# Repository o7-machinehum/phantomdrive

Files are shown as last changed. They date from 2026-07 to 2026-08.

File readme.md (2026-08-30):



Phantomdrive is open source encrypted USB drive with a stealth mechanism to hide its second partition. To decrypt it you must create a file containing your password in the format `password:addpasswordhere`, this is used to derive AES-XTS keys. The drive automatically unmounts itself, remounts the remaining disk and encrypts and decrypts in place. It uses CH569W SoC, which has USB3, SDIO and an AES hardware block. It is programmable over USB using the `wch-ch56x-isp` library.

``` bash
|-- ee             # Hardware files
|-- Makefile
|-- readme.md      # This files
|-- test           # Test the cypto components
|-- ref            # Reference docs
|-- src            # Firmware
|-- tests          # Verification scripts
|-- wch-ch56x-bsp  # Board support package
`-- wch-ch56x-isp  # Programming software
```

# Getting Started
``` bash
git submodule update --init --recursive --checkout --force
cd wch-ch56x-isp
make # Build the ISP tool
```

## Install the toolchain
The HydraUSB3 project requires the patched HydraUSB3 xPack GCC 12.2.0-1, which
supports the `WCH-Interrupt-fast` interrupt attribute:

```bash
cd /tmp
curl -sL -o riscv-gcc-xpack.tar.gz \
  "https://github.com/hydrausb3/riscv-none-elf-gcc-xpack/releases/download/12.2.0-1/xpack-riscv-none-elf-gcc-12.2.0-1-linux-x64.tar.gz"
tar xzf riscv-gcc-xpack.tar.gz
sudo cp -r xpack-riscv-none-elf-gcc-12.2.0-1/* /usr/local/
```

## Debugging
```
make UART=1 # Enable UART
```

## Build and Flashing the project

The AES mode, PBKDF2 iteration count, and locked capacity can be selected
independently. Supported KDF values are `100000` and `600000`; 100,000 is the
default. `LOCKED_SECTORS` sets the locked (decoy) capacity in 512-byte sectors
and defaults to 16,777,216 sectors (8 GiB). It must be smaller than the physical
card's sector count; otherwise the unlocked capacity calculation underflows.

``` bash
# Remove flash drive
# While holding boot button, plug in

# Build and flash AES-XTS firmware with 600,000 PBKDF2 iterations and an
# 8 GiB locked capacity
make AES_MODE=XTS KDF_ROUNDS=600000 LOCKED_SECTORS=16777216 flash

# Or build and flash AES-CTR firmware with 100,000 iterations
make AES_MODE=CTR KDF_ROUNDS=100000 flash

# Build all four AES/KDF combinations
./release.sh
```

The four builds are written to `build/CTR_100K`, `build/CTR_600K`,
`build/XTS_100K`, and `build/XTS_600K`.

## Unlocking Drive
``` bash
# This will keep your password in bash history, but fine for testing/insecure
sudo echo "password:YourPasswordHere13245" > /mnt/unlock.txt

# Or avoid keeping the password is bash history
sudo dd of=/mnt/unlock.txt
password:YourPasswordHere13245
^D # ctrl+d
```
On the same note, please ensure your text editor doesn't cash/backup files, if they do disable that or use a different editor.

# Releasing the hardware
``` bash
./scripts/release_hardware.sh
```

# Security Notes

This code has not been professionally audited. Treat Phantomdrive as an experimental open source hardware/firmware project rather than a formally reviewed security product. The current level of validation is described in the [test README](test/readme.md). I am not responsible for loss of data, security incidents, or other damage resulting from use of this project.

The encrypted area can use AES-256-CTR or AES-256-XTS, with keys derived using
PBKDF2-HMAC-SHA256 and either 100,000 or 600,000 iterations. AES mode and KDF
iteration count affect the on-disk format, so firmware built with different
settings cannot decrypt the same data without migration or reformatting.

Unlock detection is also content-based. While the device is locked, any write data containing the string `password:` can be interpreted as an unlock attempt; the file does not need to be named `unlock.txt`.

Shells may save commands in history so be aware when unlocking from the shell. Additionally, some text editors cache file contents in swap, autosave, or recovery files, etc... If you're using a text editor to enter your password disable this feature.

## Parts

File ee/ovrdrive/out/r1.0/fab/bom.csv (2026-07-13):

Designator | Value | Footprint | Quantity | Part Number
C1,C6 | 4.7uF | Capacitor_SMD:C_0402_1005Metric | 2 | CL05A475MP5NRNC
C3,C4,C8,C10,C14-C18,C21-C23,C26-C28 | 100nF | Capacitor_SMD:C_0402_1005Metric | 15 | CL05B104KP5NNNC
C7,C9,C11,C12 | 22uF | Capacitor_SMD:C_0402_1005Metric | 4 | CL05A226MQ5N6J8
C19,C20 | 15pF | Capacitor_SMD:C_0402_1005Metric | 2 | CL05C150JB5NNNC
C24,C25 | 2.2uF | Capacitor_SMD:C_0402_1005Metric | 2 | CL05A225MQ5NNNC
J2 | USB3_A | Connector_USB:USB3_A_Plug_Wuerth_692112030100_Horizontal | 1 | XUSM-0930-231
J4 | Micro_SD_Card_Det_Hirose_DM3AT | Connector_Card:microSD_HC_Hirose_DM3AT-SF-PEJM5 | 1 | DM3AT-SF-PEJM5
L1,L2 | 2.2uH | Inductor_SMD:L_Changjiang_FTC303015D | 2 | SRN3015-2R2M
R1,R2,R4,R5 | 100k | Capacitor_SMD:C_0402_1005Metric | 4 | RC0402FR-07100KL
R3 | 450k | Capacitor_SMD:C_0402_1005Metric | 1 | RC0402FR-07453KL
RN1,RN2 | 47k | Resistor_SMD:R_Array_Concave_4x0402 | 2 | CAT10-473J4LF
SW1 | SW_Push | Button_Switch_SMD:SW_Push_SPST_NO_Alps_SKRK | 1 | SKRKAEE020
U1 | CH569W | Package_DFN_QFN:QFN-68-1EP_8x8mm_P0.4mm_EP5.2x5.2mm | 1 | CH569W
U2,U3 | TLV62569DBV | Package_TO_SOT_SMD:SOT-23-5 | 2 | TLV62569DBV
U5-U7 | TPD2EUSB30 | Package_TO_SOT_SMD:Texas_DRT-3 | 3 | TPD2EUSB30DRTR
Y2 | 30Mhz | Crystal:Crystal_SMD_3225-4Pin_3.2x2.5mm | 1 | ABM8-30.000MHZ-12-B1U-T

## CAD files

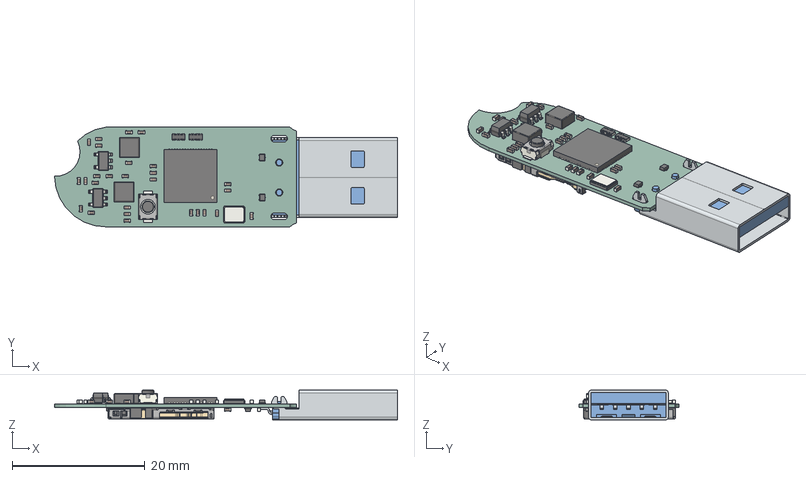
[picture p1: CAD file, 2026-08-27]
ee/ovrdrive/out/r1.0/ovrdrive.step
51.6 x 15.0 x 4.50 mm
C_0402_1005Metric x 33
DRT_3 x 3
SOT-23-5 x 2
R_Array_Concave_4x0402 x 2
L_Changjiang_FTC303015D x 2
SW_Push_SPST_NO_Alps_SKRK
Crystal_SMD_3225-4Pin_3.2x2.5mm
QFN_68_1EP_8x8mm_P04mm_EP52x52mm
microSD_HC_Hirose_DM3AT-SF-PEJM5
692112030100_Housing
692112030100_Shielding
692112030100_Pin2
692112030100_Pin3 x 2
692112030100_Pin1 x 5
692112030100_Housing2
692112030100_Pin5
ovrdrive_PCB

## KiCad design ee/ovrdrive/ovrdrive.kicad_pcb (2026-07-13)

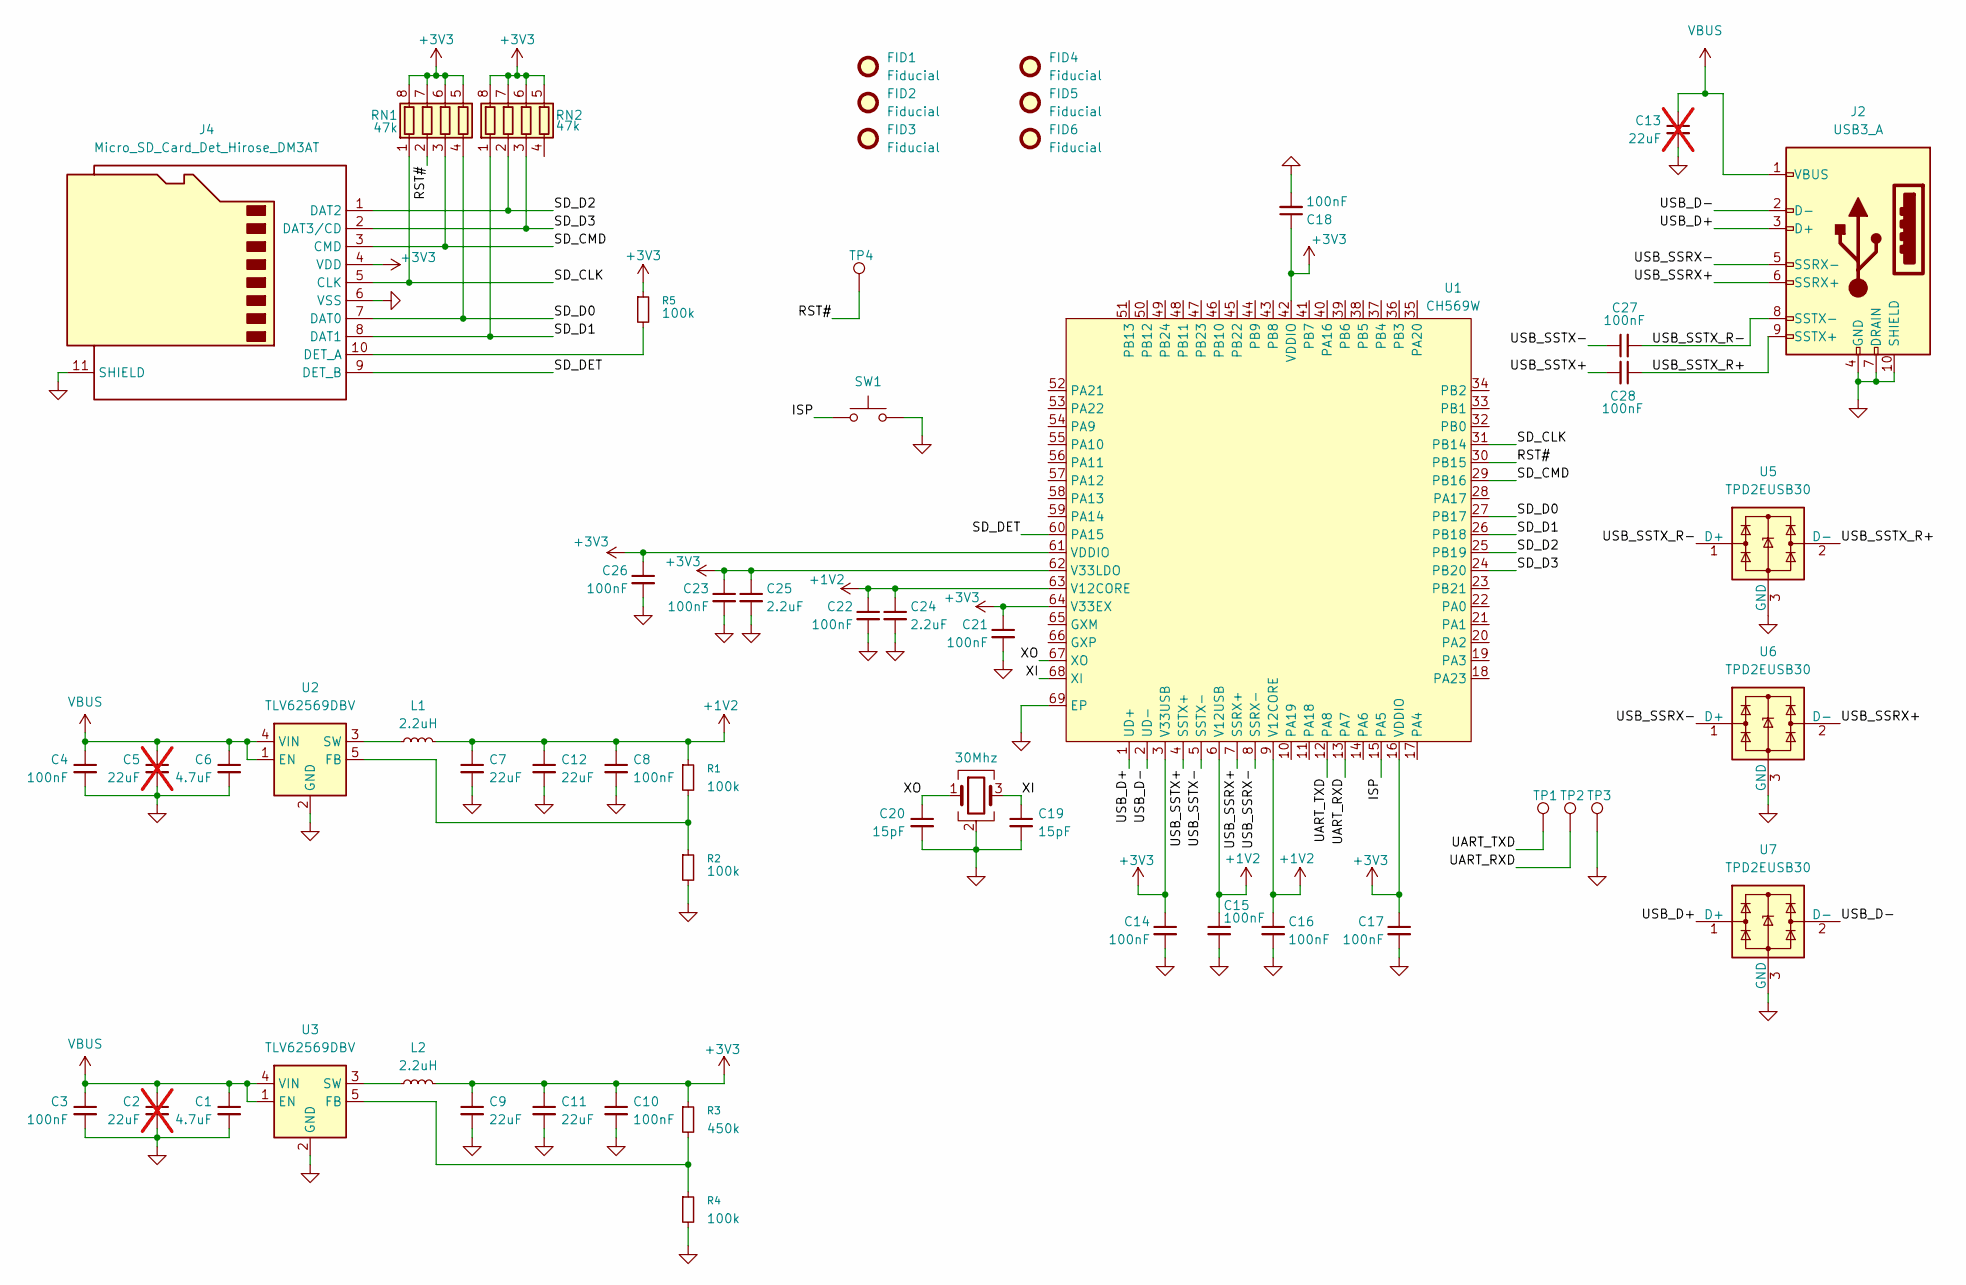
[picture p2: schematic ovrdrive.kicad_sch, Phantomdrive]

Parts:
C1, C6: 4.7uF; C_0402_1005Metric; MPN CL05A475MP5NRNC
C2, C5, C13: 22uF; C_0402_1005Metric; MPN CL05A226MQ5N6J8; not fitted
C3, C4, C8, C10, C14, C15, C16, C17, C18, C21, C22, C23, C26, C27, C28: 100nF; C_0402_1005Metric; MPN CL05B104KP5NNNC
C7, C9, C11, C12: 22uF; C_0402_1005Metric; MPN CL05A226MQ5N6J8
C19, C20: 15pF; C_0402_1005Metric; MPN CL05C150JB5NNNC
C24, C25: 2.2uF; C_0402_1005Metric; MPN CL05A225MQ5NNNC
FID1, FID2, FID3, FID4, FID5, FID6: Fiducial; Fiducial_0.5mm_Mask1mm; MPN DNP
J2: USB3_A; USB3_A_Plug_Wuerth_692112030100_Horizontal; MPN XUSM-0930-231
J4: Micro_SD_Card_Det_Hirose_DM3AT; microSD_HC_Hirose_DM3AT-SF-PEJM5; MPN DM3AT-SF-PEJM5
L1, L2: 2.2uH; L_Changjiang_FTC303015D; MPN SRN3015-2R2M
R1, R2, R4, R5: 100k; C_0402_1005Metric; MPN RC0402FR-07100KL
R3: 450k; C_0402_1005Metric; MPN RC0402FR-07453KL
RN1, RN2: 47k; R_Array_Concave_4x0402; MPN CAT10-473J4LF
SW1: SW_Push; SW_Push_SPST_NO_Alps_SKRK; MPN SKRKAEE020
TP1, TP2, TP3, TP4: TestPoint; TestPoint_Pad_1.0x1.0mm; MPN DNP
U1: CH569W; QFN-68-1EP_8x8mm_P0.4mm_EP5.2x5.2mm; MPN CH569W
U2, U3: TLV62569DBV; SOT-23-5; MPN TLV62569DBV
U5, U6, U7: TPD2EUSB30; Texas_DRT-3; MPN TPD2EUSB30DRTR
Y2: 30Mhz; Crystal_SMD_3225-4Pin_3.2x2.5mm; MPN ABM8-30.000MHZ-12-B1U-T

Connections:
+1V2: C7.1, C8.1, C12.1, C15.1, C16.1, C22.1, C24.1, L1.2, R1.1, U1.6 (V12USB), U1.9 (V12CORE), U1.63 (V12CORE)
+3V3: C9.1, C10.1, C11.1, C14.1, C17.1, C18.1, C21.1, C23.1, C25.1, C26.1, J4.4 (VDD), L2.2, R3.1, R5.1, RN1.5 (R4.2), RN1.6 (R3.2), RN1.7 (R2.2), RN1.8 (R1.2), RN2.5 (R4.2), RN2.6 (R3.2), RN2.7 (R2.2), RN2.8 (R1.2), U1.3 (V33USB), U1.16 (VDDIO), U1.42 (VDDIO), U1.61 (VDDIO), U1.62 (V33LDO), U1.64 (V33EX)
/ISP: SW1.1, U1.15 (PA5)
/RST#: RN1.2 (R2.1), TP4.1 (1_1), U1.30 (PB15)
/SD_CLK: J4.5 (CLK), RN1.1 (R1.1), U1.31 (PB14)
/SD_CMD: J4.3 (CMD), RN1.3 (R3.1), U1.29 (PB16)
/SD_D0: J4.7 (DAT0), RN1.4 (R4.1), U1.27 (PB17)
/SD_D1: J4.8 (DAT1), RN2.1 (R1.1), U1.26 (PB18)
/SD_D2: J4.1 (DAT2), RN2.2 (R2.1), U1.25 (PB19)
/SD_D3: J4.2 (DAT3/CD), RN2.3 (R3.1), U1.24 (PB20)
/SD_DET: J4.9 (DET_B), U1.60 (PA15)
/UART_RXD: TP2.1 (1_1), U1.13 (PA7)
/UART_TXD: TP1.1 (1_1), U1.12 (PA8)
/USB_D+: J2.3 (D+), U1.1 (UD+), U7.1 (D+)
/USB_D-: J2.2 (D-), U1.2 (UD-), U7.2 (D-)
/USB_SSRX+: J2.6 (SSRX+), U1.7 (SSRX+), U6.2 (D-)
/USB_SSRX-: J2.5 (SSRX-), U1.8 (SSRX-), U6.1 (D+)
/USB_SSTX+: C28.2, U1.4 (SSTX+)
/USB_SSTX-: C27.1, U1.5 (SSTX-)
/USB_SSTX_R+: C28.1, J2.9 (SSTX+), U5.2 (D-)
/USB_SSTX_R-: C27.2, J2.8 (SSTX-), U5.1 (D+)
/XI: C19.1, U1.68 (XI), Y2.3
/XO: C20.1, U1.67 (XO), Y2.1
GND: C1.2, C2.2, C3.2, C4.2, C5.2, C6.2, C7.2, C8.2, C9.2, C10.2, C11.2, C12.2, C13.2, C14.2, C15.2, C16.2, C17.2, C18.2, C19.2, C20.2, C21.2, C22.2, C23.2, C24.2, C25.2, C26.2, J2.4 (GND), J2.7 (DRAIN), J2.10 (SHIELD), J4.6 (VSS), J4.11 (SHIELD), R2.2, R4.2, SW1.2, TP3.1 (1_1), U1.69 (EP), U2.2 (GND), U3.2 (GND), U5.3 (GND), U6.3 (GND), U7.3 (GND), Y2.2 (G), Y2.4 (G)
unnamed: J4.10 (DET_A), R5.2
unnamed: R1.2, R2.1, U2.5 (FB)
unnamed: L1.1, U2.3 (SW)
unnamed: R3.2, R4.1, U3.5 (FB)
unnamed: L2.1, U3.3 (SW)
VBUS: C1.1, C2.1, C3.1, C4.1, C5.1, C6.1, C13.1, J2.1 (VBUS), U2.1 (EN), U2.4 (VIN), U3.1 (EN), U3.4 (VIN)

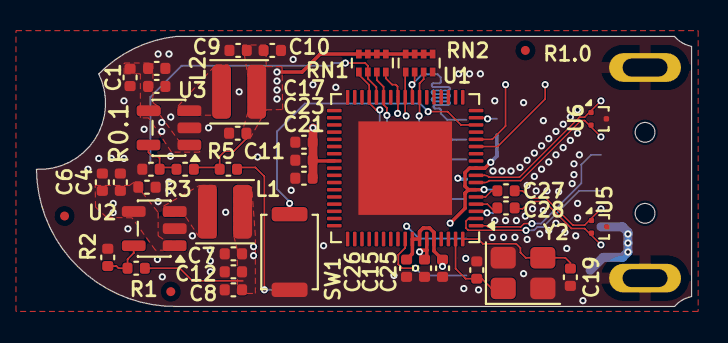
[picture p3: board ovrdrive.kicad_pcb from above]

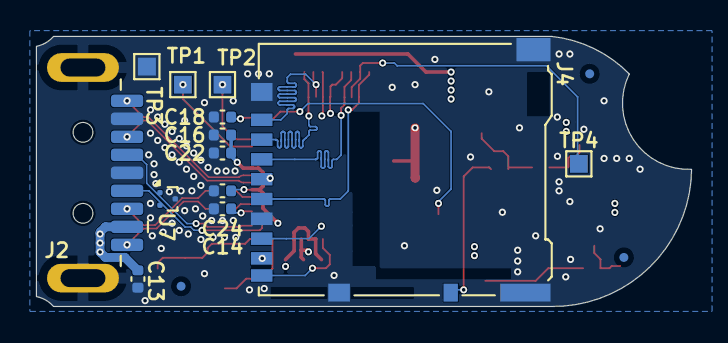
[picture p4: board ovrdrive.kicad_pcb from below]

Board: 4 copper layers, 36.4 x 15.0 mm, 57 parts (16 on the bottom side), 30 nets.

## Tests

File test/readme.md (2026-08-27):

# Tests
These tests are used to verify the functionality of the device.

## Integrity Tests
These are tests that verify the devices works as a flash drive, check speeds, read/writes are working etc.

``` bash
# f3 Can be used to write and then read back some data to verify
sudo mount /dev/sda1 /mnt/ # Mount the drive
f3write /mnt/
f3read /mnt/
```

This test was also done after removing the disk, inserting, unlocking, and running f3read to ensure data survives a cycle like this.

## Encryption Tests
These are tests to verify the cryptographic functions are working.
Build them with `KDF_ROUNDS` set to the same value as the firmware.

### SHA256 implementation

``` bash
cd test
make sha256_test # To test the sha256 function
./build/sha256_test
```

### PBKDF2-HMAC-SHA256 implementation

``` bash
cd test
make pbkdf2_test KDF_ROUNDS=600000
./build/pbkdf2_test
```

This compares the project KDF at 600,000 iterations against OpenSSL.

### AES-CTR Test

First write data through an unlocked Phantomdrive running the AES-CTR firmware,
then unmount it, remove the SD card, and insert the SD card into the computer.
Set the password and device salt in `ctr_test.c`. You can find the salt with:

``` bash
udevadm info --query=property --name=/dev/sdc | grep ID_SERIAL_SHORT
ID_SERIAL_SHORT=HydraUSB3_SN:34FC1FA7145467F7
```

Then fill out the required values in `ctr_test.c`:

``` C
const uint8_t password[] = "pineapple";
uint8_t salt[KDF_SALT_SIZE] = {0x34, 0xfc, 0x1f, 0xa7, 0x14, 0x54, 0x67, 0xf7};
```

``` bash
make ctr_test
sudo ./build/ctr_test /dev/sdX
sudo losetup -Pf --show unencrypted.blob
sudo mount /dev/loop0p1 /mnt/
# Verify your files. You can use f3 if you like.
```

`ctr_test` reads the ciphertext actually written by the device, derives the key
with the project KDF, and decrypts it with OpenSSL AES-256-CTR.

### AES-XTS Test

First write data through an unlocked Phantomdrive running the AES-XTS firmware,
then unmount it, remove the SD card, and insert the SD card into the computer.
Set the password and device salt in `xts_test.c`, then decrypt the raw SD card:

``` bash
cd test
make xts_test
sudo ./build/xts_test /dev/sdX
sudo losetup -Pf --show unencrypted.blob
sudo mount /dev/loop0p1 /mnt/
```

`xts_test` reads the ciphertext actually written by the device, derives the data
and tweak keys with the project KDF, and decrypts it with OpenSSL AES-256-XTS.

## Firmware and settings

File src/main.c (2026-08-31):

/* main.c - USB MSC device: Host <-> CH569 USB2 <-> SD card
 * SPDX-License-Identifier: Apache-2.0
 */
#include "CH56x_common.h"
#include "debug.h"

#include "CH56x_usb20_devbulk.h"
#include "CH56x_usb_devbulk_desc_cmd.h"

#include "bot.h"
#include "scsi_tables.h"
#include "sd.h"
#include "phantomdrive.h"
#include "crypto.h"

#undef FREQ_SYS
#define FREQ_SYS (120000000)

#if(defined DEBUG)
#define UART1_BAUD (115200)
#endif

debug_log_buf_t log_buf;

#define FLASH_ROMA_UID_ADDR (0x77fe4)
usb_descriptor_serial_number_t unique_id;

usb_descriptor_usb_vid_pid_t vid_pid =
{
	.vid = { .id_16b = 0x1209 },
	.pid = { .id_16b = 0x2833 }
};

static const char usb_product[] = "Phantomdrive";
static const char usb_vendor[] = "Rootkitlabs";
static const char scsi_vendor[] = "RKlabs"; /* SCSI vendor is limited to 8 characters. */


/* Init: GPIO/BSP -> UART -> SD -> PhantomDrive -> USB -> main loop */
int main()
{
	bsp_gpio_init();
	bsp_init(FREQ_SYS);
	log_init(&log_buf);

#if(defined DEBUG)
	UART1_init(UART1_BAUD, FREQ_SYS);
#endif
	cprintf("\n\r");
	log_printf("Phantomdrive, ChipID(Hex)=%02X\r\n", SYS_GetChipID());

	memset(&unique_id, 0, 8);
	FLASH_ROMA_READ(FLASH_ROMA_UID_ADDR, (uint32_t*)&unique_id, 8);

	log_printf("Phantomdrive FW v1.0 (CPr Freq=%d MHz)\r\n", (FREQ_SYS/1000000));

	log_printf("Initializing SD card...\r\n");
	uint8_t sta = SDCardInit(&TF_EMMCParam);

	if(sta != OP_SUCCESS)
	{
		log_printf("SD init FAILED (sta=%d)\r\n", sta);
		while(1) {} // Something's wrong, sit here forever
	}

	/* Enable eMMC error IRQ after init (BKGAP/TRANDONE polled in data path) */
	PFIC_EnableIRQ(EMMC_IRQn);
	TF_EMMCParam.EMMCOpErr = 0;

	log_printf("SD OK: %d sectors (%d MB)\r\n",
		TF_EMMCParam.EMMCSecNum,
		TF_EMMCParam.EMMCSecNum / 2048);
	phantomdrive_init(unique_id.sn_64b);
	scsi_inquiry_set_identity(scsi_vendor, usb_product);

	/* Expose USB only after the SD-backed volume is fully initialized. */
	R32_USB_CONTROL = 0;
	usb_descriptor_set_string_serial_number(&unique_id);
	usb_descriptor_set_usb_vid_pid(&vid_pid);
	usb_descriptor_set_string_vendor(usb_vendor);
	usb_descriptor_set_string_product(usb_product);
	PFIC_EnableIRQ(USBHS_IRQn);
	USB20_Device_Init(ENABLE);

	log_printf("MSC ready\r\n");
	while(1)
	{
		bot_poll();
	}
}

__attribute__((interrupt("WCH-Interrupt-fast"))) void HardFault_Handler(void)
{
	printf("HardFault\r\n");
	printf(" SP=0x%08X\r\n", __get_SP());
	printf(" MIE=0x%08X\r\n", __get_MIE());
	printf(" MSTATUS=0x%08X\r\n", __get_MSTATUS());
	printf(" MCAUSE=0x%08X\r\n", __get_MCAUSE());
	bsp_wait_ms_delay(1);
}

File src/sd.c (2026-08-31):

/********************************** (C) COPYRIGHT *******************************
 * File Name          : sd.c
 * Description        : SD card initialization driver
 *
 * This file implements SD card initialization using the CH569's eMMC controller.
 * The CH569 has a single "eMMC" controller that handles both eMMC and SD cards.
 * SD cards use a different init sequence than eMMC, so this file provides
 * SD-specific versions of OCR reading, RCA assignment, CSD parsing, etc.
 *
 * The init sequence follows the SD Physical Layer Spec (Section 4.2):
 *   CMD0 (reset) → CMD8 (voltage check) → ACMD41 (capacity negotiation) →
 *   CMD2 (read CID) → CMD3 (get RCA) → CMD9 (read CSD) → CMD7 (select) →
 *   ACMD6 (set 4-bit bus) → ACMD51 (read SCR)
 *
 * After init, the card is in Transfer State and ready for data commands
 * (CMD17/18 for read, CMD24/25 for write).
 *
 * Hardware interface:
 *   CLK  = PB15 (bSDCK)          - SD clock output
 *   CMD  = PB14 (bSDCMD)         - SD command line (bidirectional)
 *   DAT0 = PB17                  - SD data line 0
 *   DAT1 = PB18                  - SD data line 1
 *   DAT2 = PB19                  - SD data line 2
 *   DAT3 = PB20                  - SD data line 3
 *   [CH569DS1.PDF: GPIO Pin Multiplexing, eMMC Controller]
 *
 * Clock configuration:
 *   Base clock = 480MHz (from PLL)
 *   LOWEMMCCLK divider = 0x1F (31) for card initialization
 *   SD_HIGH_SPEED_CLK_DIV = 10 for 48MHz after CMD6 high-speed selection
 *   [ref/SD_Physical_Layer_Spec_v6.00.pdf: Section 6 - Clock Control]
 *
 * SPDX-License-Identifier: Apache-2.0
 *******************************************************************************/
#include "sd.h"
#include "debug.h"
#include <string.h>

#define SD_SWITCH_STATUS_LEN        64

/* Largest response is the 64-byte CMD6 status. CH569 DMA requires a 16-byte
 * aligned address in RAMX. */
static __attribute__((aligned(16))) uint8_t scr_buf[SD_SWITCH_STATUS_LEN]
	__attribute__((section(".DMADATA")));

#define SD_CMD6_CHECK_HIGH_SPEED    0x00FFFFF1u
#define SD_CMD6_SET_HIGH_SPEED      0x80FFFFF1u
#define SD_SWITCH_G1_HIGH_SPEED     0x02
#define SD_SWITCH_G1_RESULT_MASK    0x0F
#define SD_HIGH_SPEED_CLK_DIV       EMMCCLK_48  /* 480MHz / 10 = 48MHz */
/*******************************************************************************
 * SDReadOCR - Read SD card Operating Conditions Register via ACMD41
 *
 * SD cards use ACMD41 (CMD55 prefix + CMD41) instead of CMD1 (eMMC).
 * This negotiates voltage range and determines card capacity type.
 *
 * The host sends:
 *   CMD55 (APP_CMD prefix, tells card next command is application-specific)
 *   ACMD41 with arg 0x40FF8000:
 *     Bit 30 (HCS=1): Host supports SDHC/SDXC
 *     Bits 23-0: Voltage window (3.2-3.4V range)
 *
 * Card responds with OCR register:
 *   Bit 31: Power-up complete (busy bit, polled until set)
 *   Bit 30: Card Capacity Status (CCS): 1=SDHC/SDXC, 0=SDSC
 *
 * [ref/SD_Physical_Layer_Spec_v6.00.pdf: Section 4.2.3 - ACMD41]
 ******************************************************************************/
static uint8_t SDReadOCR(PSD_PARAMETER pEMMCPara)
{
	uint8_t  i;
	uint32_t cmd_arg_val;
	uint16_t cmd_set_val;
	uint8_t  sta = 0;
	uint32_t cmd_rsp_val;

	/* Poll ACMD41 up to 100 times (~2 seconds total with delays).
	 * SD spec requires at most 1 second for power-up. */
	for(i = 0; i < 100; i++)
	{
		/* CMD55 - APP_CMD prefix (required before every ACMD)
		 * [ref/SD_Physical_Layer_Spec_v6.00.pdf: Section 4.3.9 - CMD55] */
		cmd_arg_val = 0;
		cmd_set_val = RB_EMMC_CKIDX | RB_EMMC_CKCRC | RESP_TYPE_48 | 55;
		EMMCSendCmd(cmd_arg_val, cmd_set_val);
		mDelayuS(2);
		while(1)
		{
			sta = CheckCMDComp(pEMMCPara);
			if(sta != CMD_NULL) break;
		}
		if(sta == CMD_FAILED)
		{
			mDelaymS(20);
			continue;
		}

		/* ACMD41 - SD_SEND_OP_COND
		 * Arg: 0x40FF8000 = HCS bit set + voltage window
		 * No CRC/index check on response (R3 response type) */
		cmd_arg_val = 0x40FF8000;
		cmd_set_val = RESP_TYPE_48 | 41;
		EMMCSendCmd(cmd_arg_val, cmd_set_val);
		mDelayuS(2);
		while(1)
		{
			sta = CheckCMDComp(pEMMCPara);
			if(sta != CMD_NULL) break;
		}
		if(sta == CMD_SUCCESS)
		{
			/* Read OCR from response register
			 * [CH569DS1.PDF: R32_EMMC_RESPONSE3 holds R3/R1 response] */
			cmd_rsp_val = R32_EMMC_RESPONSE3;
			if(cmd_rsp_val & (1<<31))  /* Bit 31: power-up complete */
			{
				if(cmd_rsp_val & (1<<30))  /* Bit 30: CCS - SDHC/SDXC */
					pEMMCPara->EMMCType = EMMCIO_HIGH_CAPACITY_SD_CARD;
				else
					pEMMCPara->EMMCType = EMMCIO_CAPACITY_SD_CARD_V2_0;
				break;
			}
		}
		mDelaymS(20);
	}
	if(i == 100) return OP_FAILED;
	return sta;
}

/*******************************************************************************
 * SDSetRCA - Get Relative Card Address (CMD3)
 *
 * For SD cards, CMD3 (SEND_RELATIVE_ADDR) causes the card to publish its
 * own RCA. This differs from eMMC where the host assigns the RCA.
 * The RCA is in bits [31:16] of the R6 response.
 *
 * [ref/SD_Physical_Layer_Spec_v6.00.pdf: Section 4.3.1 - CMD3]
 ******************************************************************************/
static uint8_t SDSetRCA(PSD_PARAMETER pEMMCPara)
{
	uint32_t cmd_arg_val;
	uint16_t cmd_set_val;
	uint8_t  sta;

	/* For SD cards, CMD3 arg is 0 (card chooses its own RCA) */
	cmd_arg_val = 0;
	cmd_set_val = RB_EMMC_CKIDX | RB_EMMC_CKCRC | RESP_TYPE_48 | EMMC_CMD3;
	EMMCSendCmd(cmd_arg_val, cmd_set_val);
	while(1)
	{
		sta = CheckCMDComp(pEMMCPara);
		if(sta != CMD_NULL) break;
	}
	if(sta == CMD_SUCCESS)
	{
		/* Extract RCA from upper 16 bits of R6 response */
		pEMMCPara->EMMC_RCA = R32_EMMC_RESPONSE3 >> 16;
	}
	return sta;
}
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

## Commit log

2026-06-09 V1.0-rc1
    The salt is now derived from the UID of the device. Debug is snubbed in a cleaner way. Tests adapted
2026-07-13 Hardware r1.0-rc1
    [bom.csv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]
2026-07-13 Hardware r1.0 release.
    [ovrdrive-B_Cu.gbl, ovrdrive-B_Fab.gbr, ovrdrive-B_Mask.gbs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]
2026-07-13 Removed the extern in the header and replaced with helper functions to get the state. Added a check so the PC will be denied cyphertext if it tries to access it.
    [emmc_ops.h]
2026-07-13 Implemented AES-XTS, there is a switch so usere can choose between CTR or XTS. Right now CTR is at about 9MB/s write and 20MB/s read. While XTS is at 6MB/s write and 10MB/s read.
2026-07-13 Those don't need to be in DMA memory or 16 byte alligned.
2026-08-27 Regenerated with the same hardware.
    [ovrdrive-B_Cu.gbl, ovrdrive-B_Fab.gbr, ovrdrive-B_Mask.gbs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]
2026-08-30 Refactored code and removed failure paths for things that will never happen.
    [main.c]
2026-08-31 Allow changing of device ID.
